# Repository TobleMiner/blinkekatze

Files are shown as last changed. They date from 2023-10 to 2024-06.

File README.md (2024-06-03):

Blinkekatze 😺
=============

This is a replacement PCB for one version of cat themed night lights available via various online retailers.

It adds a number of RGB LEDs, sensors and wireless connectivity, enabling an interactive light display synchronized over a large number of Blinkekatzen.

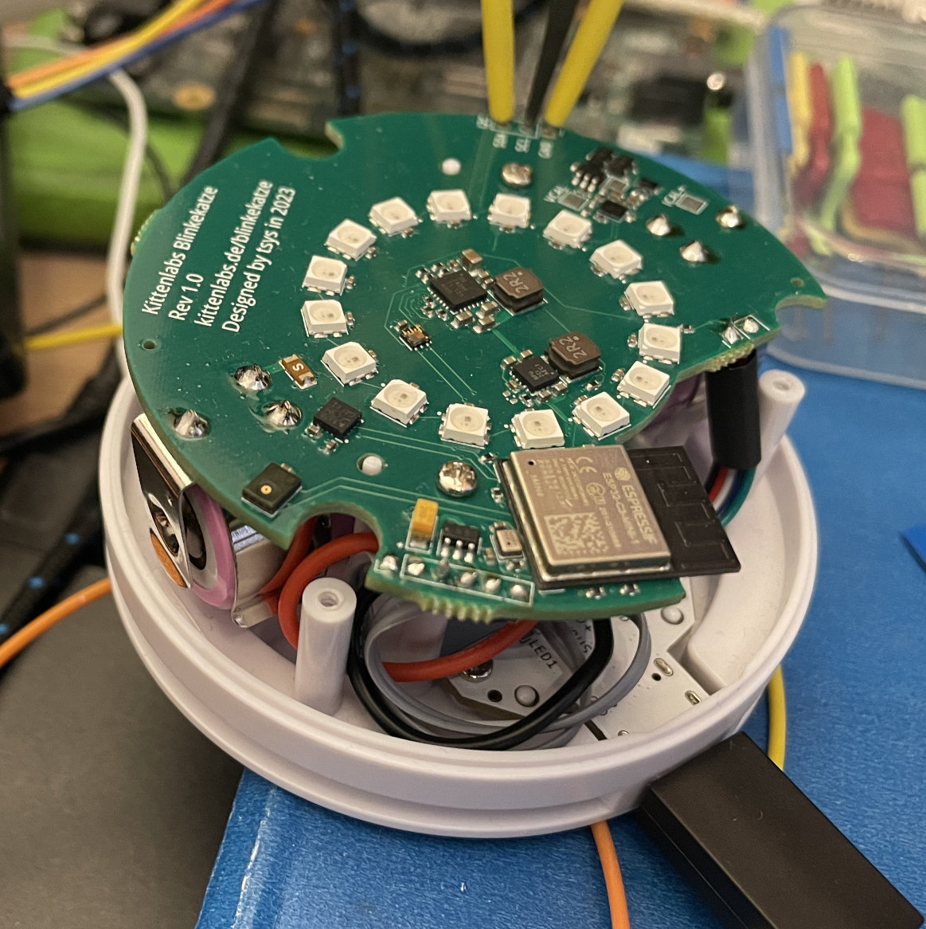
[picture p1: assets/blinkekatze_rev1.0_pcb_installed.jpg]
Photo of Rev1.0 mainboard


Inspired by the wonderful [derf](https://github.com/derf)

# Architecture

The Blinkekatze is comprised of three PCBs:
 - The main board (this directory)
 - The USB board (located in [/usb-board](/usb-board))
 - The original power- and mode-switch board from the nightlight

## Mainboard

The main board contains most elements critical to device operation. At its heart is an ESP32-C3 for control.

The ESP32-C3 is accompanied by the following peripherals:
 - 16 super bright, individually controllable RGB LEDs (effectively ~12bit RGB color control)
 - High precision battery gauge for accurate capacity tracking and runtime estimation
 - Accelerometer and barometer to detect user interaction
 - Ambient light sensor enabling automatic brightness control
 - Efficient buck-mode battery charger

The main board also includes a MEMS PDM microphone that could be used for audio synchronization of lighting effects.
However note the ESP32-C3 is missing hardware PDM to PCM conversion capability.

## USB board

The USB board replaces the original board used for charging in the nightlight. It offers USB connectivity to the
ESP32-C3 and contains two indicator LEDs visible through the bottom of the Blinkekatze.

To facilitate easy, solderless assembly mainboard and USB board are connected by a 5cm long 16 pin flat flex cable with opposite side contacts.

# Ordering PCBs

All PCBs required to build Blinkekatzen can be ordered fully assembled from JLCPCB. The necessary fabrication files are located in [/fab](/fab) for
the main board and [/usb-board/fab](/usb-board/fab). It is recommended to always use the latest revision available in those folders.  
When ordering the PCBs they should be ordered as 1.6mm 4 layers for the mainboard and 1.6mm 2 layers for the USB board.

## PCB assembly

In addition to the bare PCBs JLCPCB also offers an assembly service. The BOM and component centroid files required for assembly are also located in
[/fab](/fab) and [/usb-board/fab](/usb-board/fab) respectively.  
When ordering assembly for the main PCB cost can be reduced significantly by choosing to populate only the top side of the PCB and later assembling
the battery contacts (BTT1 and BTT2) on the bottom side by yourself manually. Those are the only parts on the bottom side of the PCB. Also microphone
U6 is best left unpopulated since a lack of proper PDM to PCM support on the ESP32-C3 makes it mostly unusable.

### Additional required electronic components

Apart from the components assembled by JLCPCB the following parts are required:  
 - 2x MYOUNG MY-18650-01 battery contacts (if not assembled by JLCPCB, see previous section)
 - 1x 5cm 16pin 0.5mm pitch flat flex cable (e.g. C5151983 on LCSC)
 - 1x 18650 battery (Samsung INR18650-35E recommended)

### JLCPCB assembly component availability

Sometimes components required for assembly are out of stock at JLCPCB. In this case the parts have to be ordered fist through
JLCPCB's parts preorder service. Usually all required parts can be preordered in small quantities and will be available within
a couple of days.

# Assembling the Blinkekatzen

## Preparing the PCB

If the battery contacts were not assembled through JLCPCB they need to be soldered. The overall fit of the battery is best with the
contacts installed as far apart as possible within the throughholes. Special care should be taken to ensure the battery contacts are
not soldered at an angle but lie flat on the PCB. Otherwise the battery might not snap into the contacts properly.

## Preparing the housing

In the first step the rubber boot needs to be removed. The puck containing all electronics can either be pulled out to the bottom or
first pushed into the puck and then removed.  
Next the transparent diffuser on top of the puck can be removed by undoing the three screws (relatively long and skinny #0 Phillips
head screwdriver required) and pulling up on the diffuser.  

## Removing the original PCBs

The original PCB is held in place with two screws. After undoing the screws the PCB can be pivoted to the side and the battery unplugged.  
The original USB board also needs to be removed by undoing the two screws holding it in place.  
Finally the PCB can be freed by desoldering the six connections on the original main PCB that go to the switch board in the bottom of the case.
Since the switch board will be reused desoldering rather than cutting the wire can save some time later.  

## Modifying the case

After removal of the original main PCB the case needs to be modified slightly to accommodate the new battery. To make space for the new battery
and battery holder snip out the two thin plastic walls with the half circle shaped cutouts the old battery was resting on using flush cutters.

## Installing the USB board

The first new component to be installed in the housing is the new USB board. Since this board will be installed with the USB connector and flat
flex connector facing down the flat flex cable needs to be connected to this board first. To connect the flat flex cable the latch on the
connector must be flipped up and the cable then inserted with the contacts facing down. The cable is then secured by closing the latch again.  
Now the USB board can be installed in the housing and secured in place with the two screws.

## Installing the new main PCB

As a first step the two outermost contacts of the ribbon cable earlier desoldered from the original main PCB are soldered to the power key header
J1 on the new main PCB (labeled PWR_ON and VBAT, polarity does not matter). Then the battery is installed (here polarity does very much matter). **NEVER**
may batteries without or with a damaged insulating sleeve be used with this device. The battery contacts will short out such batteries!  
After folding back the flat flex cable so it remains free and is not trapped under the battery the new main PCB is fixed in place with two screws.  
As a final step the flat flex cable is now installed into the flat flex connector on the new main PCB in the same manner as on the USB board.

## Firmware flashing

Please see [blinkekatze-firmware](https://github.com/TobleMiner/blinkekatze-firmware) for details on firmware flashing.

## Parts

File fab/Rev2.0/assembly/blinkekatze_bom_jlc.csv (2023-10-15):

Comment | Designator | Footprint | LCSC Part #
B+ | BTT1 | MY-18650-01_flat-top | C2979183
B- | BTT2 | MY-18650-01_flat-top | C2979183
100nF | C1,C2,C3,C4,C5,C6,C7,C8,C9,C10,C11,C12,C13,C14,C15,C16,C73,C20,C21,C22,C23,C24,C26,C27 | C_0402_1005Metric | C1525
10uF | C17 | CP_EIA-3216-18_Kemet-A | C7171
1uF | C18,C19,C66,C67,C68,C69,C70,C25,C33 | C_0402_1005Metric | C52923
22uF | C28 | C_0805_2012Metric | C45783
4.7uF | C29 | C_0402_1005Metric | C23733
10uF | C30,C31,C32 | C_0603_1608Metric | C19702
10uF | C65,C71,C72,C74,C75 | C_0402_1005Metric | C15525
SK6812MINI-012 | D1,D2,D3,D4,D5,D6,D7,D8,D9,D10,D11,D12,D13,D14,D15,D16 | XXXX12-X1 | C2886570
4A | F1 | Fuse_1206_3216Metric | C187596
USB board | J4 | 0.5K-QX-16PWB_16Pin_0.5mm | C2919481
2.2uH | L4,L2 | L_Taiyo-Yuden_MD-4040 | C98361
AO3400A | Q1,Q2 | SOT-23 | C20917
10k | R1,R21,R22,R43,R9,R13,R14,R15,R16,R17,R18 | R_0402_1005Metric | C25744
100R | R2,R5,R6,R7,R10,R11,R12 | R_0402_1005Metric | C25076
220R | R3 | R_0402_1005Metric | C25091
10mR | R4 | R_0805_2012Metric | C5185583
1k | R8 | R_0402_1005Metric | C11702
330 | R19,R20 | R_0402_1005Metric | C25104
100k | R23,R44 | R_0402_1005Metric | C25741
4.7k | R45,R46 | R_0402_1005Metric | C25900
0R | R48 | R_0402_1005Metric | C17168
ESP32-C3-MINI-1 | U1 | ESP32-C3-MINI-1 | C2934569
BQ27546 | U2 | DSBGA-15_BQ27546_I2C_1.95x2.6mm_P0.5mm | C528629
SRV05-4 | U3 | SOT-23-6 | C85364
FM2113 | U4 | SOT-23-6 | C2832124
SPL06-001 | U5 | LGA-8_2x2.5mm_P0.65mm | C2684428
~ | U6 | ST_HCLGA-4LD_3x4mm | C503097
LTR-303ALS-01 | U7 | Lite-On_LTR-303ALS-01 | C364577
BQ24295 | U8 | QFN-24-1EP_4x4mm_P0.5mm_EP2.7x2.7mm | C165144
TPS63001 | U9 | Texas_DRC0010J_ThermalVias.3 | C28060
LIS3DH | U10 | LGA-16_3x3mm_P0.5mm_LayoutBorder3x5y | C15134

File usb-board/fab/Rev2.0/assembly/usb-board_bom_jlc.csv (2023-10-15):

Comment | Designator | Footprint | LCSC Part #
1nF | C1 | C_1206_3216Metric | C9196
GRN | D1 | LED_0603_1608Metric | C72043
RED | D2 | LED_0603_1608Metric | C2286
USB_C_Receptacle_USB2.0 | J2 | USB_C_Receptacle_Palconn_UTC16-G | C167321
Mainboard | J3 | 0.5K-QX-16PWB_16Pin_0.5mm | C2919481
5.1k | R1,R2 | R_0402_1005Metric | C25905
100k | R3 | R_0805_2012Metric | C149504

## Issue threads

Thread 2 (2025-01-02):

Replacement parts for SPL06-001 and CUM0805-15FR010?

ConiKost, 2025-01-02:
Unfortunately JLCPCB cannot get anymore the parts ```SPL06-001``` and ```CUM0805-15FR010```. As for ```SPL06-001```, they could get it, if you buy at minimum 10000pcs, which is way to much. But it looks like, that this part is EOL. Also part ```CUM0805-15FR010``` cannot be bought and they also cannot get a quotation.

Are there any recommended replacement parts, if possible?

patrick246, 2025-01-02:
I'm currently ordering too. I found some SPL06-001 from someone selling their parts. Minimum preorder volume for me is 14, not 10k. @LeoDJ found STE0805MW75R010F as a replacement for CUM0805-15FR010. It has a lower power rating, but should work.

ConiKost, 2025-01-02:
> I found some SPL06-001 from someone selling their parts. Minimum preorder volume for me is 14, not 10k.

Sure? Because JLCPCB also says 14pcs at minimum, but after order, the can't get them, as 10000pcs is minimum. But JLCPCB still lists 14pcs as order minimum..

patrick246, 2025-01-03:
I haven't actually gone through with ordering, as JLC suggested someone selling their idle parts.
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
There still seem to be some available.

TobleMiner, 2025-01-03:
Hey!
At first glance the GZP6816D seems to be a suitable replacement (footprint compatible as far as I can tell!) for the SPL06-001. However I have never tested that sensor before so it might be that there are some unforeseen issues.

For the 10mR shunt any 0805 10mR resistor will work fine. I would recommend keeping the tolerance to a maximum of 1% so that the battery capacity measurement results stay reasonably accurate. STE0805MW75R010F is a suitable replacement.

ConiKost, 2025-01-03:
JLC also replied to me with following parts should be compatible as replacement:
SPL06-001: [C83291](https://jlcpcb.com/parts/componentSearch?searchTxt=C83291) and [C22388663](https://jlcpcb.com/parts/componentSearch?searchTxt=C22388663)
CUM0805-15FR010: [C163089](https://jlcpcb.com/parts/componentSearch?searchTxt=C163089), [C601083](https://jlcpcb.com/parts/componentSearch?searchTxt=C601083) and [C346480](https://jlcpcb.com/parts/componentSearch?searchTxt=C346480)

Any opinion on that?

TobleMiner, 2025-01-03:
Oh, those are nice finds!
Especially the WF282A (C22388663) seems to be fully compatible to the SPL06-001. The BMP280 is somewhat similar in capabilities but not fully compatible.
The shunts are fine, too.

Closed 2025-04-13.

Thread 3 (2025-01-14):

Firmware does not find BQ27546?

ConiKost, 2025-01-14:
Since I placed an order on JLCPCB for something else, I also did order two assembled Blinkekatze PCBs (with BOM as intended) for some fun.

Can I run a test without connected switch board? My switchboard seems to have only five wires, not six.

It looks like, that flashing the firmware, it does not find the BQ27546? Could be those PCBs or parts faulty? I have _not_ enabled flashing ti battery gauge. Or could be no firmware flashed at all on the BQ27546, so it's not detected? Is there any cheaper alternative to EV2400, if this could be the case?

Monitor indicates some crashing:
```
Executing action: monitor
Running idf_monitor in directory /home/xxx/Downloads/blinkekatze-firmware
Executing "/root/.espressif/python_env/idf5.1_py3.10_env/bin/python /home/xxx/Downloads/blinkekatze-firmware/esp-idf/tools/idf_monitor.py -p /dev/ttyACM0 -b 115200 --toolchain-prefix riscv32-esp-elf- --target esp32c3 --revision 4 --decode-panic backtrace /home/xxx/Downloads/blinkekatze-firmware/build/blinkekatze.elf -m '/root/.espressif/python_env/idf5.1_py3.10_env/bin/python' '/home/xxx/Downloads/blinkekatze-firmware/esp-idf/tools/idf.py' '-p' '/dev/ttyACM0'"...
--- esp-idf-monitor 1.5.0 on /dev/ttyACM0 115200
--- Quit: Ctrl+] | Menu: Ctrl+T | Help: Ctrl+T followed by Ctrl+H
 (31ESP-ROM:esp32c3-api1-20210207
Build:Feb  7 2021
rst:0x15 (USB_UART_CHIP_RESET),boot:0x9 (SPI_FAST_FLASH_BOOT)
Saved PC:0x4004c0d4
SPIWP:0xee
mode:DIO, clock div:1
load:0x3fcd5820,len:0x1704
load:0x403cc710,len:0x938
load:0x403ce710,len:0x2ef4
entry 0x403cc710
I (24) boot: ESP-IDF v5.1.5 2nd stage bootloader
I (24) boot: compile time Jan 14 2025 13:31:15
I (25) boot: chip revision: v0.4
I (27) boot.esp32c3: SPI Speed      : 80MHz
I (32) boot.esp32c3: SPI Mode       : DIO
I (37) boot.esp32c3: SPI Flash Size : 4MB
I (42) boot: Enabling RNG early entropy source...
I (47) boot: Partition Table:
I (51) boot: ## Label            Usage          Type ST Offset   Length
I (58) boot:  0 phy_init         RF data          01 01 00009000 00001000
I (65) boot:  1 otadata          OTA data         01 00 0000a000 00002000
I (73) boot:  2 nvs              WiFi data        01 02 0000c000 00004000
I (80) boot:  3 factory          factory app      00 00 00010000 00150000
I (88) boot:  4 ota_0            OTA app          00 10 00160000 00150000
I (95) boot:  5 ota_1            OTA app          00 11 002b0000 00150000
I (103) boot: End of partition table
I (107) boot: Defaulting to factory image
I (112) esp_image: segment 0: paddr=00010020 vaddr=3c090020 size=2a528h (173352) map
I (148) esp_image: segment 1: paddr=0003a550 vaddr=3fc92e00 size=02b04h ( 11012) load
I (150) esp_image: segment 2: paddr=0003d05c vaddr=40380000 size=02fbch ( 12220) load
I (156) esp_image: segment 3: paddr=00040020 vaddr=42000020 size=8a970h (567664) map
I (252) esp_image: segment 4: paddr=000ca998 vaddr=40382fbc size=0fc98h ( 64664) load
I (271) boot: Loaded app from partition at offset 0x10000
I (271) boot: Disabling RNG early entropy source...
I (271) cpu_start: Unicore app
I (275) cpu_start: Pro cpu up.
I (290) cpu_start: Pro cpu start user code
I (290) cpu_start: cpu freq: 160000000 Hz
I (290) cpu_start: Application information:
I (293) cpu_start: Project name:     blinkekatze
I (299) cpu_start: App version:      fcac468-dirty
I (304) cpu_start: Compile time:     Jan 14 2025 13:31:08
I (310) cpu_start: ELF file SHA256:  40c822aebe1f46a8...
I (316) cpu_start: ESP-IDF:          v5.1.5
I (321) cpu_start: Min chip rev:     v0.4
I (326) cpu_start: Max chip rev:     v1.99
I (331) cpu_start: Chip rev:         v0.4
I (335) heap_init: Initializing. RAM available for dynamic allocation:
I (343) heap_init: At 3FC9BAE0 len 00024520 (145 KiB): DRAM
I (349) heap_init: At 3FCC0000 len 0001C710 (113 KiB): DRAM/RETENTION
I (356) heap_init: At 3FCDC710 len 00002950 (10 KiB): DRAM/RETENTION/STACK
I (363) heap_init: At 50000010 len 00001FD8 (7 KiB): RTCRAM
I (370) spi_flash: detected chip: generic
I  (374) spi_flash: flash io: dio
I (379) sleep: Configure to isolate all GPIO pins in sleep state
I (385) sleep: Enable automatic switching of GPIO sleep configuration
I (392) app_start: Starting scheduler on CPU0
I (397) main_task: Started on CPU0
I (397) main_task: Calling app_main()
I (397) gpio: GPIO[0]| InputEn: 0| OutputEn: 0| OpenDrain: 0| Pullup: 1| Pulldown: 0| Intr:0
I (397) gpio: GPIO[2]| InputEn: 0| OutputEn: 0| OpenDrain: 0| Pullup: 1| Pulldown: 0| Intr:0
E (497) I2C_BUS: I2C bus timeout, trying to unstick bus
I (497) gpio: GPIO[0]| InputEn: 0| OutputEn: 0| OpenDrain: 0| Pullup: 1| Pulldown: 0| Intr:0
I (497) gpio: GPIO[2]| InputEn: 0| OutputEn: 0| OpenDrain: 0| Pullup: 1| Pulldown: 0| Intr:0
E (497) BQ27546: Failed to read gauge id: 263
E (597) I2C_BUS: I2C bus timeout, trying to unstick bus
I (597) gpio: GPIO[8]| InputEn: 0| OutputEn: 0| OpenDrain: 0| Pullup: 1| Pulldown: 0| Intr:0
I (597) gpio: GPIO[2]| InputEn: 0| OutputEn: 0| OpenDrain: 0| Pullup: 1| Pulldown: 0| Intr:0
E (597) BQ27546: Failed to read gauge id: 263
ESP_ERROR_CHECK failed: esp_err_t 0x107 (ESP_ERR_TIMEOUT) at 0x420062a2
--- 0x420062a2: app_main at /home/xxx/Downloads/blinkekatze-firmware/main/src/main.c:267 (discriminator 1)

file: "./main/src/main.c" line 233
func: app_main
expression: bq27546_init(&gauge, &i2c_bus)

abort() was called at PC 0x403871dd on core 0
--- 0x403871dd: _esp_error_check_failed at /home/xxx/Downloads/blinkekatze-firmware/esp-idf/components/esp_system/esp_err.c:50

--- Stack dump detected
Core  0 register dump:
MEPC    : 0x40380694  RA      : 0x403871e8  SP      : 0x3fc9df20  GP      : 0x3fc93600
--- 0x40380694: panic_abort at /home/xxx/Downloads/blinkekatze-firmware/esp-idf/components/esp_system/panic.c:466
0x403871e8: __ubsan_include at /home/xxx/Downloads/blinkekatze-firmware/esp-idf/components/esp_system/ubsan.c:313

TP      : 0x3fc747c8  T0      : 0x37363534  T1      : 0x7271706f  T2      : 0x33323130
S0/FP   : 0x3fc9df5c  S1      : 0x3fc9df40  A0      : 0x3fc9df5c  A1      : 0x3fc9df3e
A2      : 0x00000000  A3      : 0x3fc9df89  A4      : 0x00000001  A5      : 0x3fc9b000
A6      : 0x7a797877  A7      : 0x76757473  S2      : 0x00000000  S3      : 0x3fc9b000
S4      : 0x00000000  S5      : 0x00000000  S6      : 0x00000000  S7      : 0x00000000
S8      : 0x00000000  S9      : 0x00000000  S10     : 0x3fc9b000  S11     : 0x00000000
T3      : 0x6e6d6c6b  T4      : 0x6a696867  T5      : 0x66656463  T6      : 0x62613938
MSTATUS : 0x00001801  MTVEC   : 0x40380001  MCAUSE  : 0x00000007  MTVAL   : 0x00000000
--- 0x40380001: _vector_table at ??:?

MHARTID : 0x00000000

--- Backtrace:

panic_abort (details=details@entry=0x3fc9df5c "abort() was called at PC 0x403871dd on core 0") at /home/xxx/Downloads/blinkekatze-firmware/esp-idf/components/esp_system/panic.c:466
466	    *((volatile int *) 0) = 0; // NOLINT(clang-analyzer-core.NullDereference) should be an invalid operation on targets
#0  panic_abort (details=details@entry=0x3fc9df5c "abort() was called at PC 0x403871dd on core 0") at /home/xxx/Downloads/blinkekatze-firmware/esp-idf/components/esp_system/panic.c:466
#1  0x403871e8 in esp_system_abort (details=details@entry=0x3fc9df5c "abort() was called at PC 0x403871dd on core 0") at /home/xxx/Downloads/blinkekatze-firmware/esp-idf/components/esp_system/port/esp_system_chip.c:84
#2  0x4038df64 in abort () at /home/xxx/Downloads/blinkekatze-firmware/esp-idf/components/newlib/abort.c:38
#3  0x403871e0 in _esp_error_check_failed (rc=<optimized out>, file=<optimized out>, line=<optimized out>, function=<optimized out>, expression=<optimized out>) at /home/xxx/Downloads/blinkekatze-firmware/esp-idf/components/esp_system/esp_err.c:50
#4  0x420062a6 in app_main () at /home/xxx/Downloads/blinkekatze-firmware/main/src/main.c:267
#5  0x00000000 in ?? ()
Backtrace stopped: frame did not save the PC
```

ConiKost, 2025-01-14:
I did a small test and disabled step by step ESP_ERROR_CHECK. After everything disable, the ESP-C3 boots to shell. But it looks like, that nothng is on the i2c bus? So both faultry produced and assembled PCB?

ConiKost, 2025-02-06:
@TobleMiner any idea on that?

Pusty, 2025-02-20:
I'm running into exactly the same situation.

ConiKost, 2025-02-21:
You mean, the bq27546 is not detected, because it's not programmed? The firmware offers some experimental flashing of the it gauge, but I don't know, if that works for empty gauges? Could you pass me your diff, so I could try for myself?

I still wonder, if my PCB is working, because currently, even LEDs do not turn on. But maybe it's too early in init?

Pusty, 2025-02-22:
```diff
diff --git a/main/src/bq27546.c b/main/src/bq27546.c
index 84b90d1..3e83d89 100644
--- a/main/src/bq27546.c
+++ b/main/src/bq27546.c
@@ -32,6 +32,7 @@

 static const char *TAG = "BQ27546";

+/*
 static void lock(bq27546_t *bq) {
 	xSemaphoreTake(bq->lock, portMAX_DELAY);
 }
@@ -151,7 +152,6 @@ esp_err_t bq27546_write_flash_execute_(bq27546_t *bq, const bq27546_flash_op_t *
 			ESP_LOGE(TAG, "Unknown flash operation 0x%02x, op %lu", op->type, (unsigned long)i);
 			return ESP_FAIL;
 		}
-		/* Wait one tick to ensure watchdog stays happy */
 		vTaskDelay(1);
 	}

@@ -274,3 +274,37 @@ esp_err_t bq27546_seal(bq27546_t *bq) {
 esp_err_t bq27546_it_enable(bq27546_t *bq) {
 	return run_subcmd(bq, CMD_CONTROL, SUBCMD_IT_ENABLE);
 }
+*/
+
+int bq27546_get_voltage_mv(bq27546_t *bq) {
+	return 3600;
+}
+
+int bq27546_get_temperature_0_1k(bq27546_t *bq) {
+	return 2931;
+}
+int bq27546_get_time_to_empty_min(bq27546_t *bq) {
+	return 0xffff;
+}
+
+int bq27546_get_full_charge_capacity_mah(bq27546_t *bq) {
+	return 3500;
+}
+
+
+esp_err_t bq27546_get_current_ma(bq27546_t *bq, int *current_ma_out) {
+	uint16_t ucurrent_ma = 100;
+	int16_t current_ma;
+	current_ma = (int16_t)ucurrent_ma;
+	*current_ma_out = current_ma;
+	return 0;
+}
+
+
+int bq27546_get_state_of_charge_percent(bq27546_t *bq) {
+	return 100;
+}
+
+int bq27546_get_state_of_health_percent(bq27546_t *bq) {
+	return 100;
+}
\ No newline at end of file
diff --git a/main/src/main.c b/main/src/main.c
index b9632ba..5ac18dd 100644
--- a/main/src/main.c
+++ b/main/src/main.c
@@ -224,9 +224,15 @@ void app_main(void) {
 	usb_init();

 	i2c_bus_t i2c_bus;
-	i2c_bus_init(&i2c_bus, I2C_NUM_0, 0, 2, 100000);
+	//i2c_bus_init(&i2c_bus, I2C_NUM_0, 0, 2, 100000);
+    i2c_bus_init(&i2c_bus, I2C_NUM_0, 8, 2, 100000);
+
+    is_rev2 = true;
 	bq27546_t gauge;
-	esp_err_t err =	bq27546_init(&gauge, &i2c_bus);
+
+
+    //ESP_ERROR_CHECK(bq27546_init(&gauge, &i2c_bus));
+	/*esp_err_t err =	bq27546_init(&gauge, &i2c_bus);
 	if (err) {
 		i2c_bus_deinit(&i2c_bus);
 		i2c_bus_init(&i2c_bus, I2C_NUM_0, 8, 2, 100000);
@@ -266,6 +272,7 @@ void app_main(void) {
 	int current_ma;
 	ESP_ERROR_CHECK(bq27546_get_current_ma(&gauge, &current_ma));
 	ESP_LOGI(TAG, "Battery current: %dmA", current_ma);
+    */

 	spi_bus_config_t spi_bus_cfg = {
 		.mosi_io_num = is_rev2 ? 3 : 7,

```

The LEDs are off by default, I need to either add the switch / connection for that or run the "ignore_power_switch" command for them to turn on

ConiKost, 2025-02-22:
Thanks. I applied your patch on vanilla source, but it looks like, that I have more problems, as boot continues and fails then not finding spl06 (barometer). Does your find it?

```
Rebooting...
ESP-ROM:esp32c3-api1-20210207
Build:Feb  7 2021
rst:0x3 (RTC_SW_SYS_RST),boot:0xd (SPI_FAST_FLASH_BOOT)
Saved PC:0x40380640
0x40380640: esp_restart_noos_dig at /home/xxx/Downloads/blinkekatze-firmware/esp-idf/components/esp_system/esp_system.c:64 (discriminator 1)
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
Pusty, 2025-02-23:
Hmm, yeah for me it works after initializing i2c as rev2 with `i2c_bus_init(&i2c_bus, I2C_NUM_0, 8, 2, 100000);`

ConiKost, 2025-02-23:
Well, I guess my produces PCBs must be faulty..

ConiKost, 2025-04-13:
Since no reply from developer, closing here..

Closed 2025-04-13.

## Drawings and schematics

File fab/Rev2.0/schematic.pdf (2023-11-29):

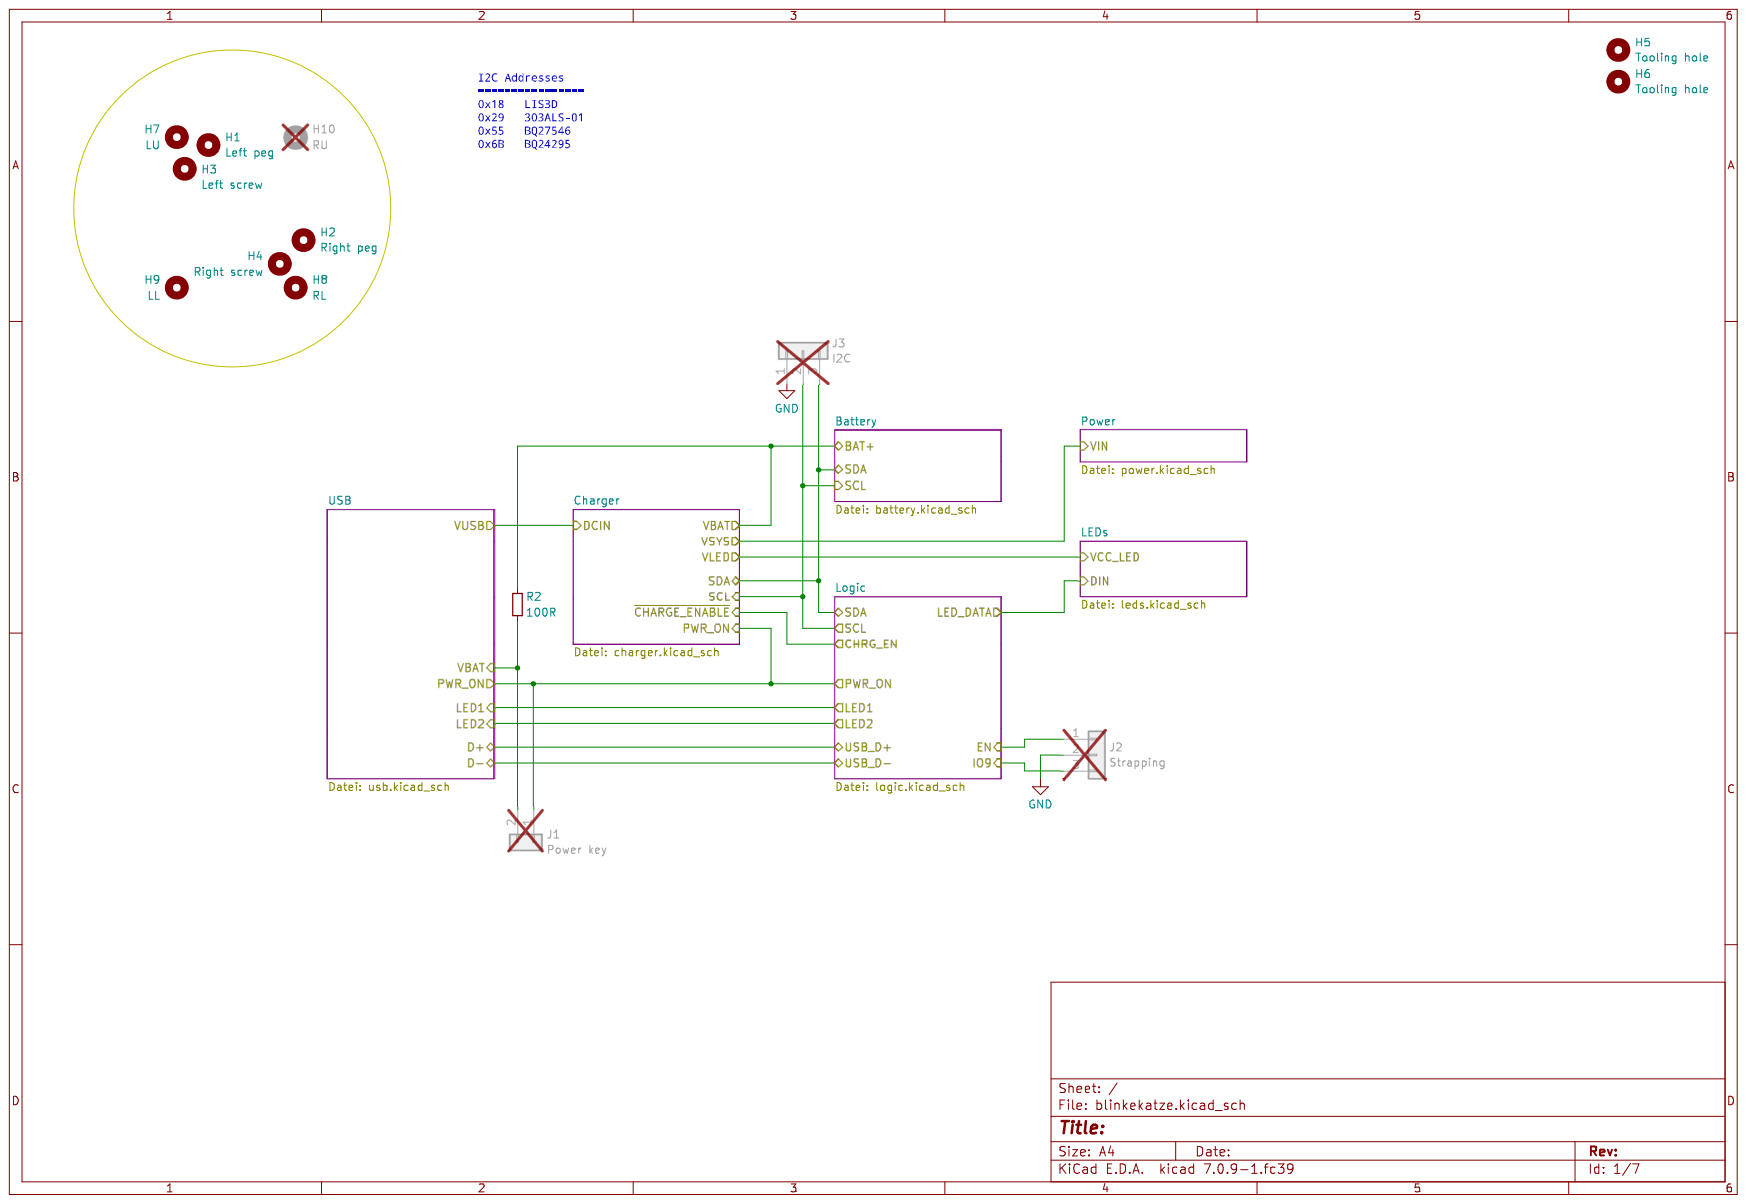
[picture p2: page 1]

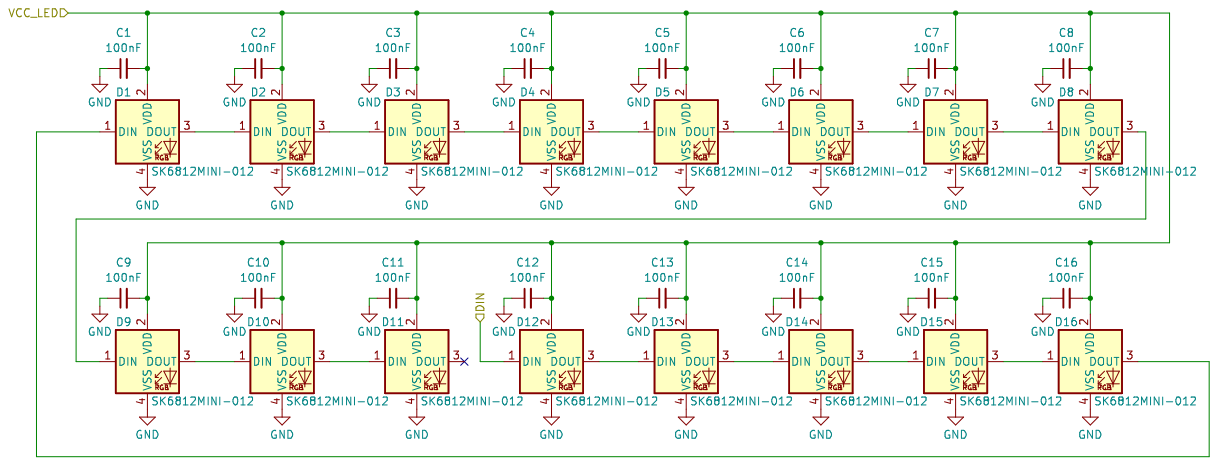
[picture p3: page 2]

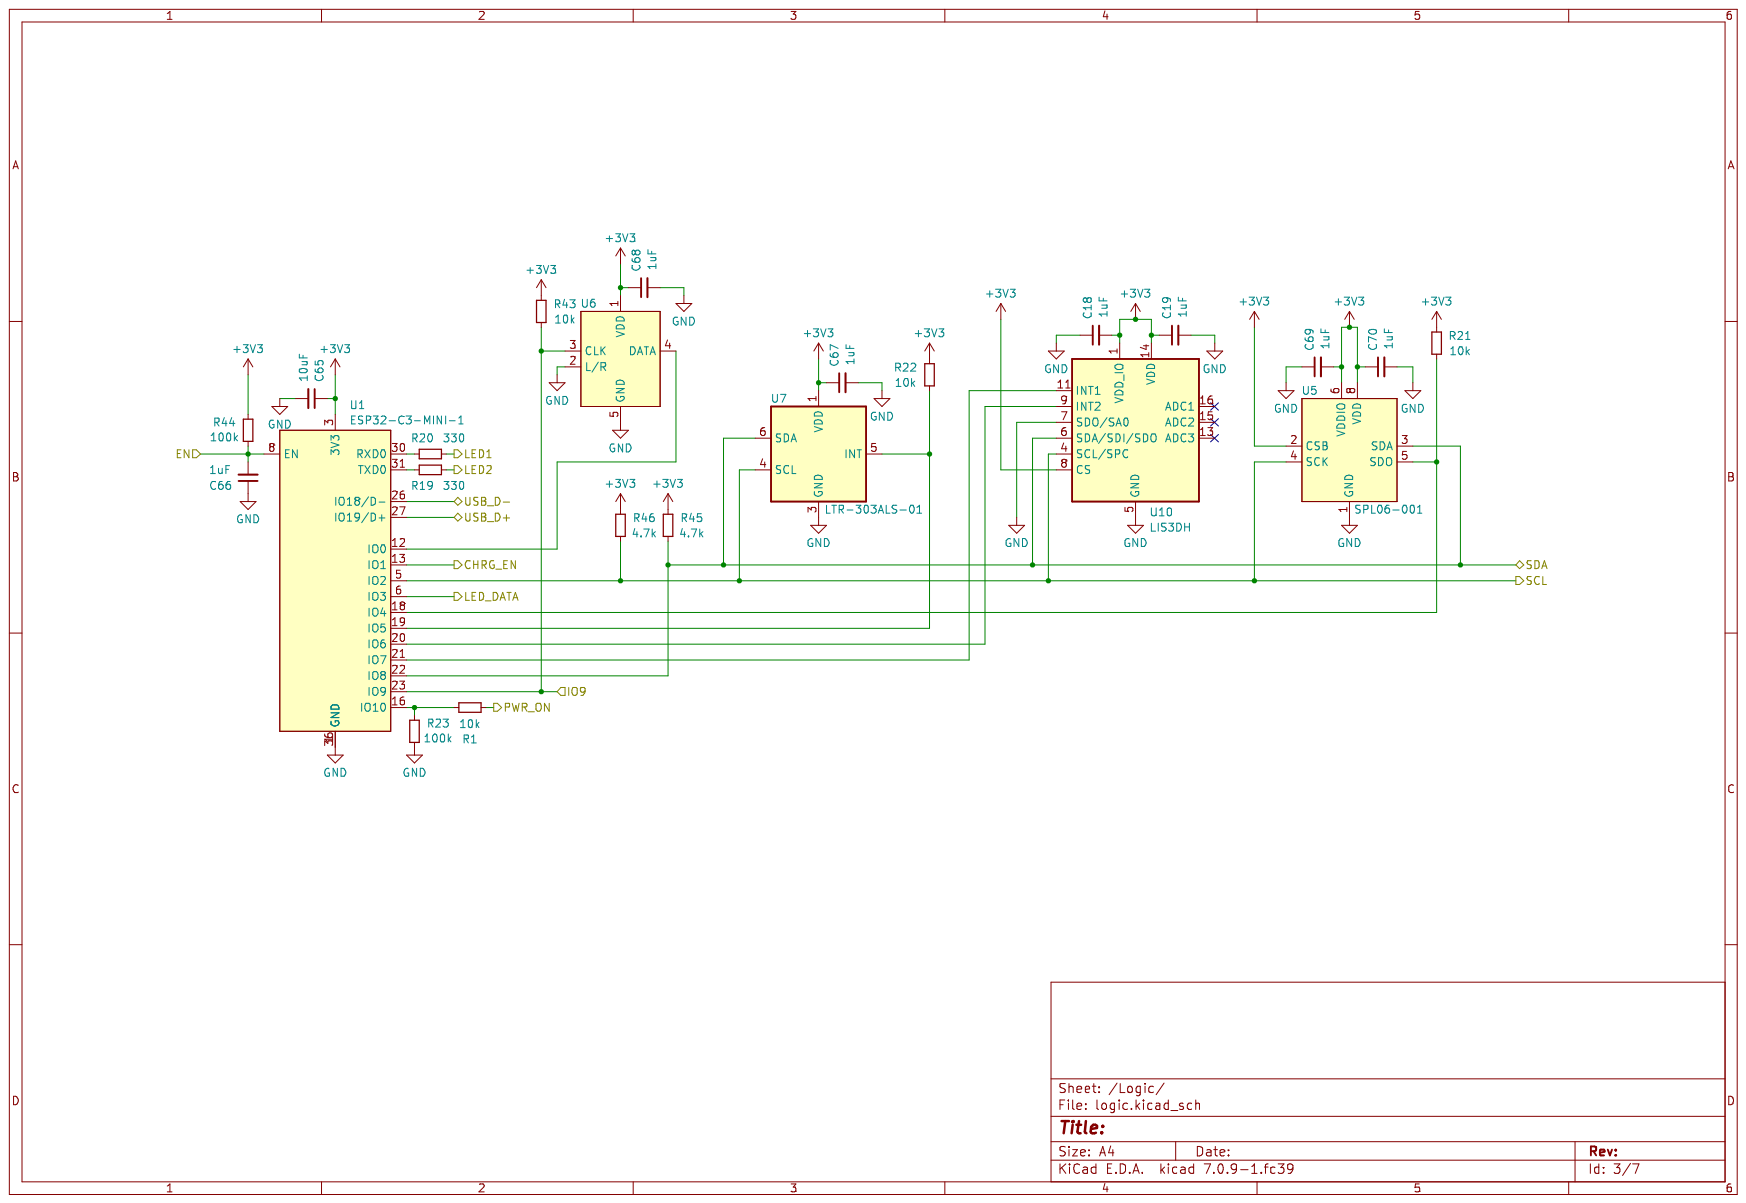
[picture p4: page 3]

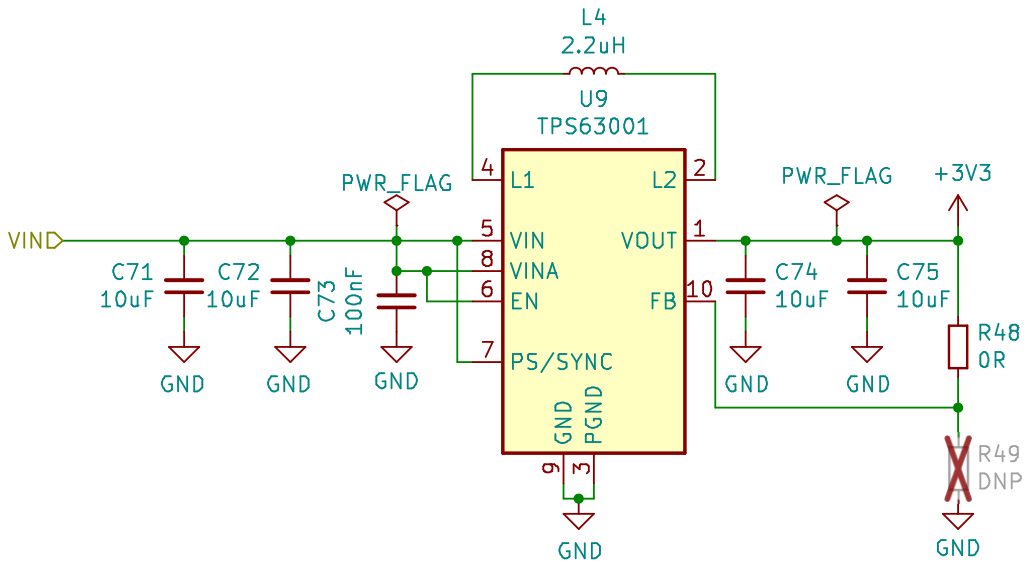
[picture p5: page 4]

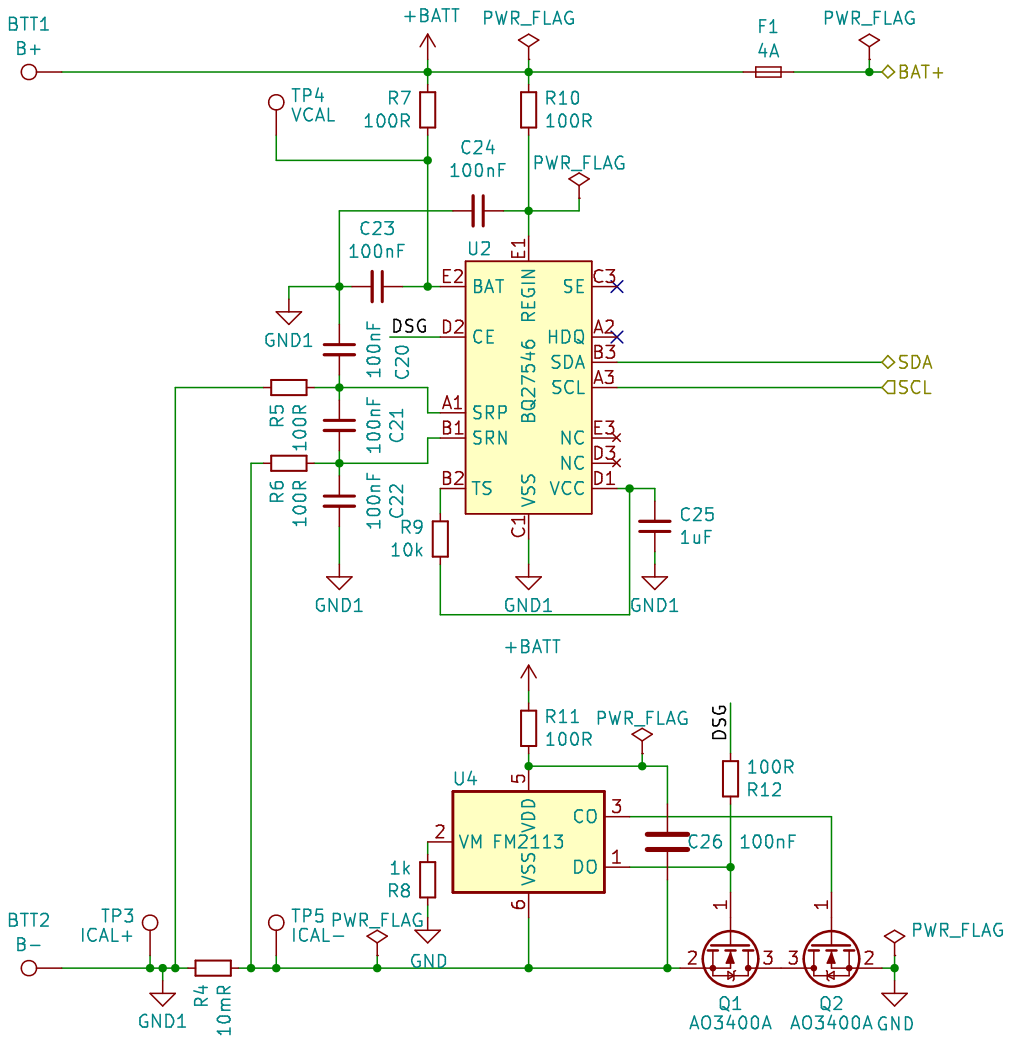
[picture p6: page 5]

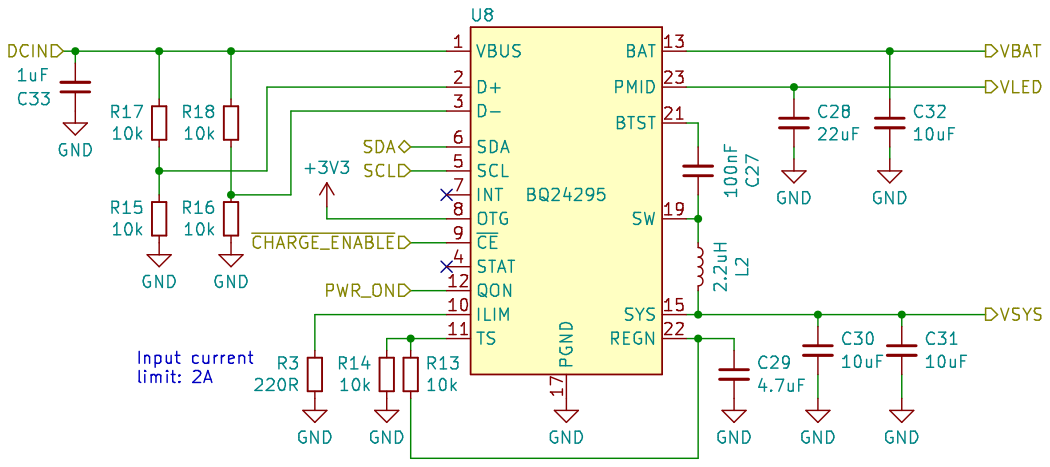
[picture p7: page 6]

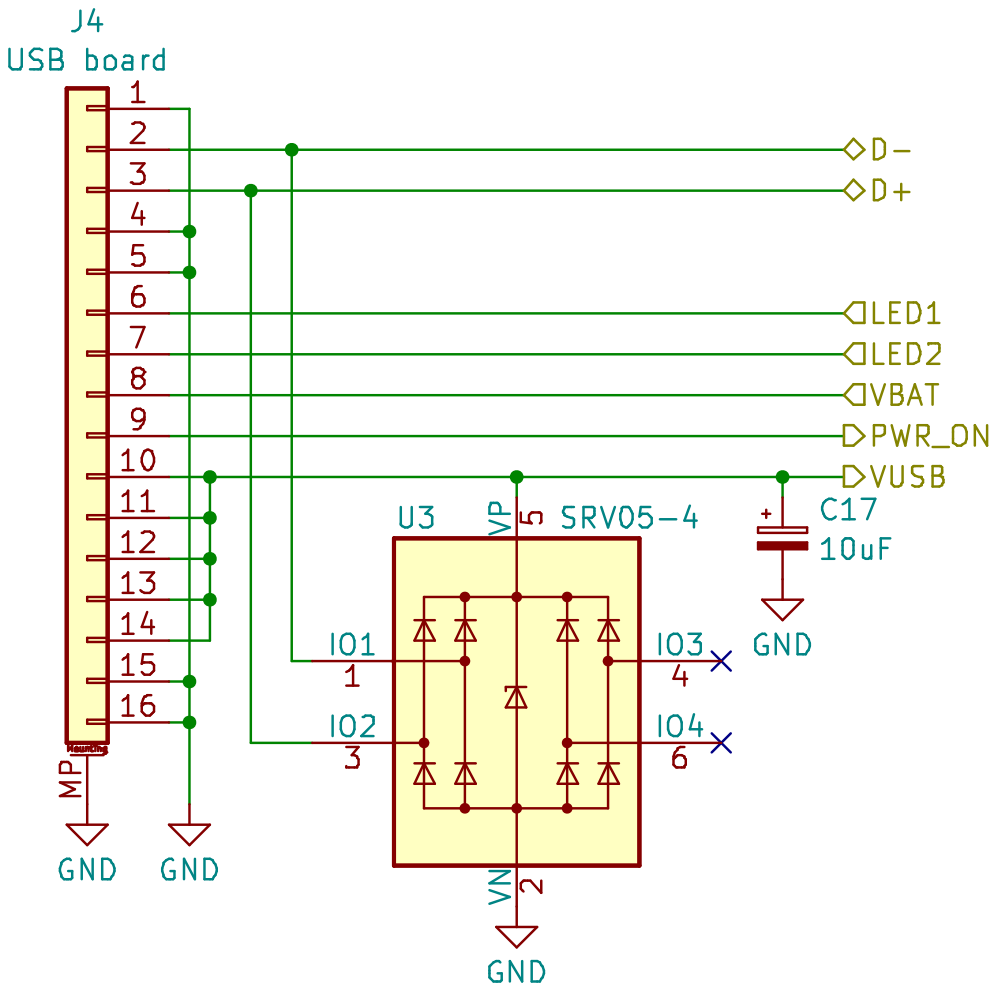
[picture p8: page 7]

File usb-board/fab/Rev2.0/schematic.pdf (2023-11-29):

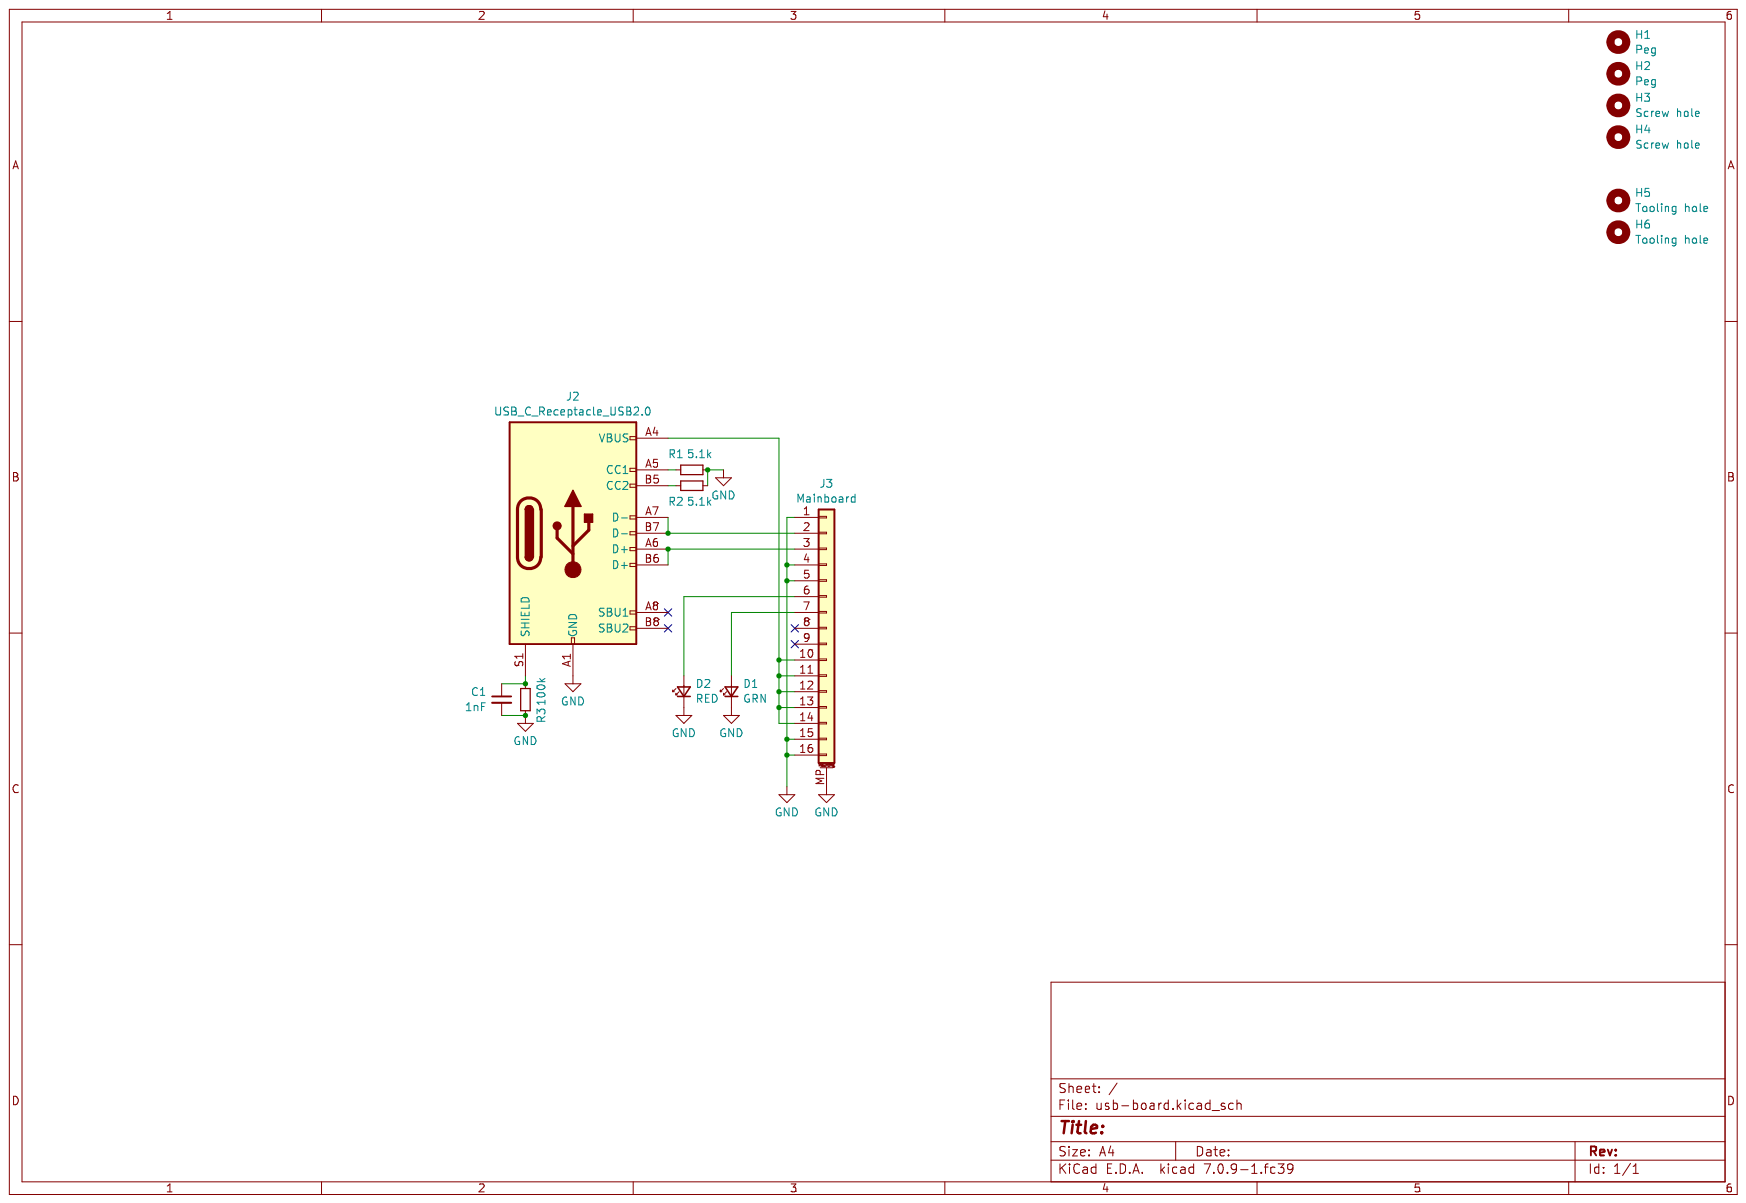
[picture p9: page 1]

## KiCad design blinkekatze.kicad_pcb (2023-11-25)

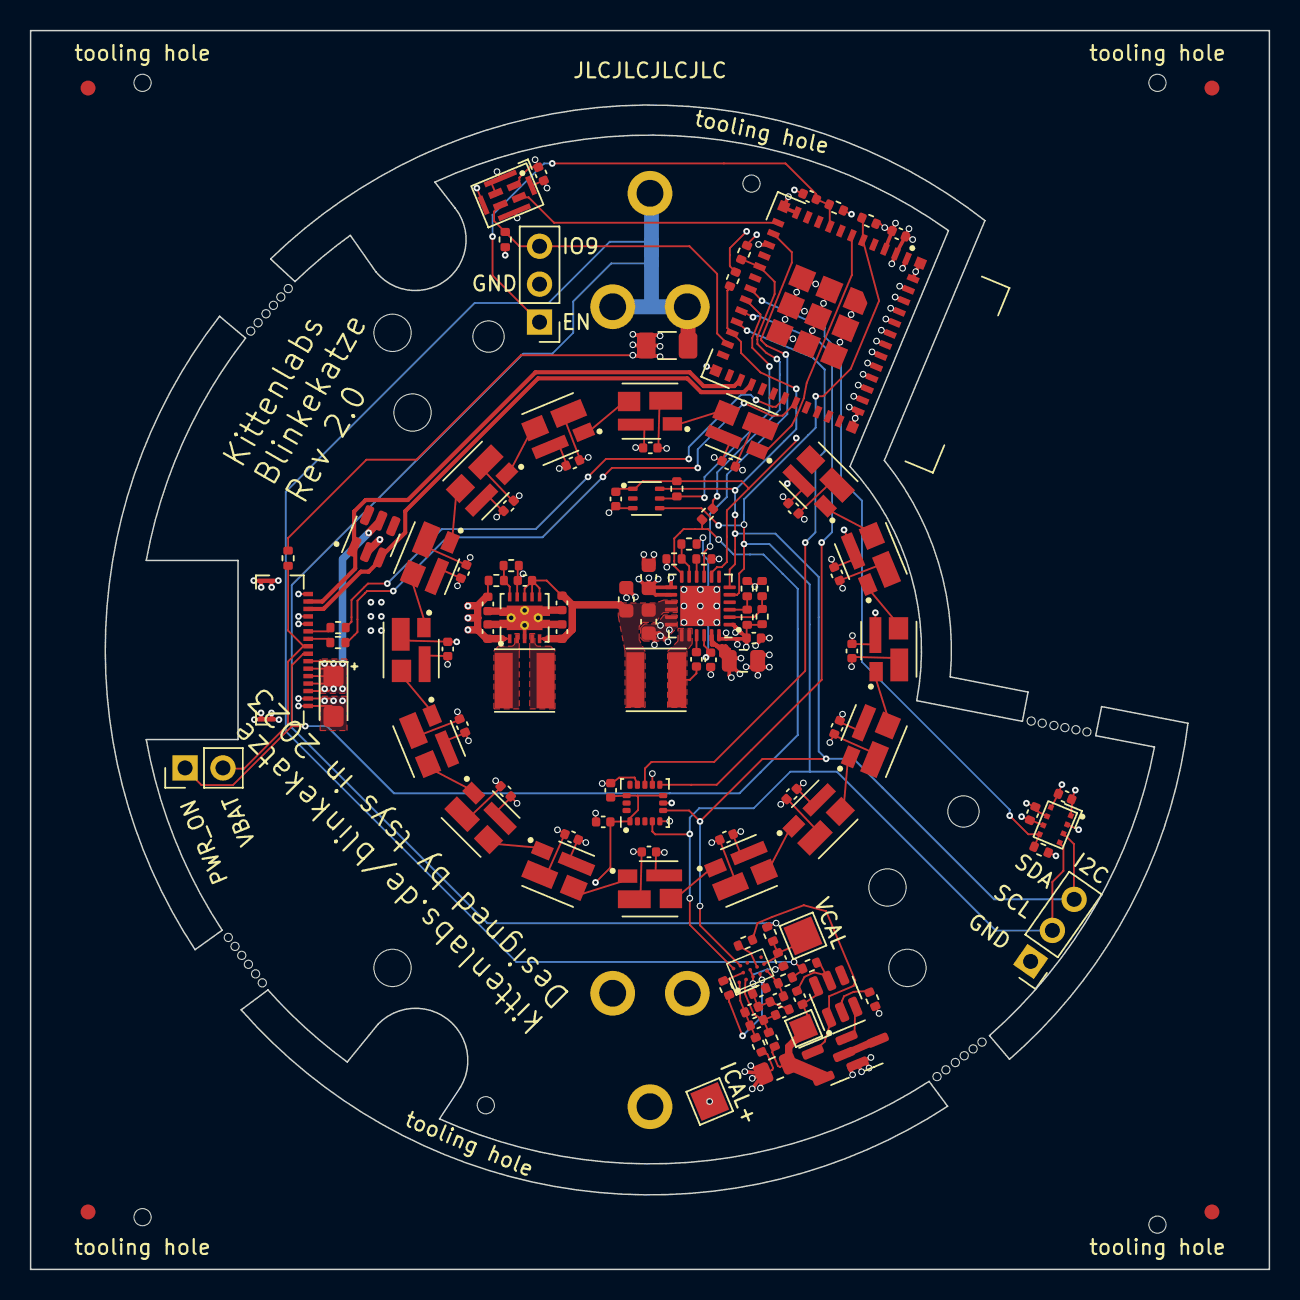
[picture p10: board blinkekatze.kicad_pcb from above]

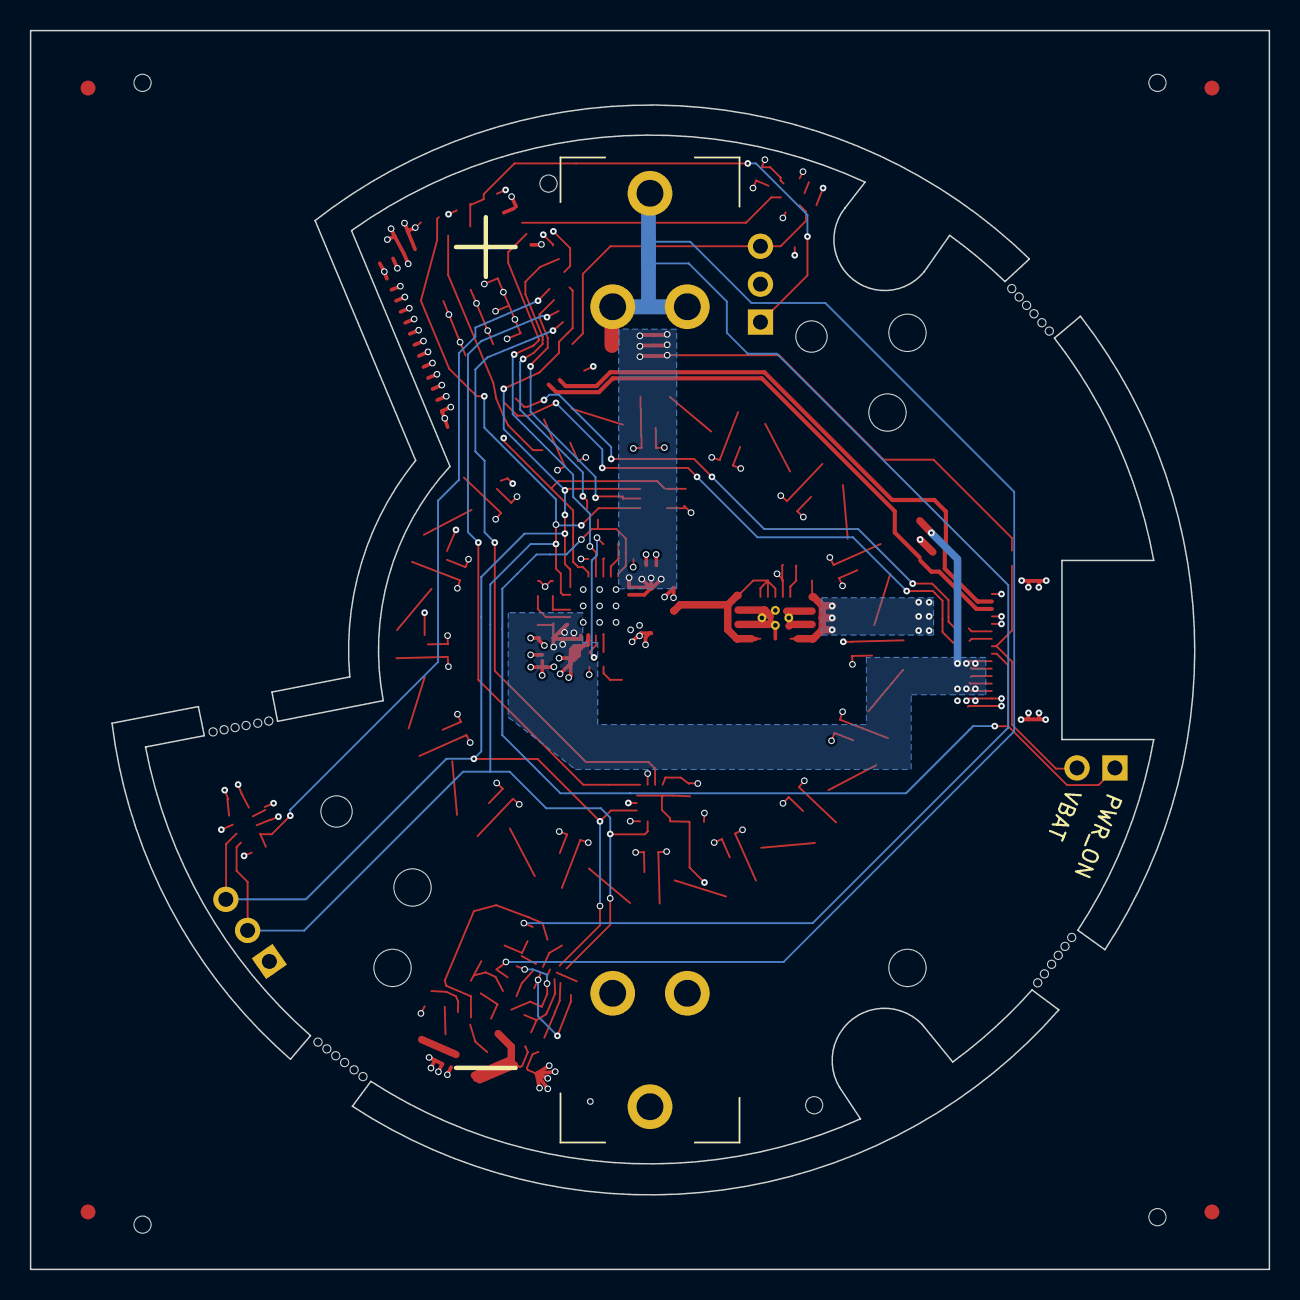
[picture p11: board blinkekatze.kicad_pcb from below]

Board: 4 copper layers, 83.0 x 83.0 mm, 122 parts (2 on the bottom side), 66 nets.

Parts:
BTT1: B+; MY-18650-01_flat-top
BTT2: B-; MY-18650-01_flat-top
C1, C2, C3, C4, C5, C6, C7, C8, C9, C10, C11, C12, C13, C14, C15, C16, C20, C21, C22, C23, C24, C26, C27, C73: 100nF; C_0402_1005Metric
C17: 10uF; CP_EIA-3216-18_Kemet-A
C18, C19, C25, C33, C66, C67, C68, C69, C70: 1uF; C_0402_1005Metric
C28: 22uF; C_0805_2012Metric
C29: 4.7uF; C_0402_1005Metric
C30, C31, C32: 10uF; C_0603_1608Metric
C65, C71, C72, C74, C75: 10uF; C_0402_1005Metric
D1, D2, D3, D4, D5, D6, D7, D8, D9, D10, D11, D12, D13, D14, D15, D16: SK6812MINI-012; XXXX12-X1
F1: 4A; Fuse_1206_3216Metric
H1: Left peg; MountingHole_2.1mm
H2: Right peg; MountingHole_2.1mm
H3: Left screw; MountingHole_2.5mm
H4: Right screw; MountingHole_2.5mm
H5, H6: Tooling hole; ToolingHole_JLCSMT
H7: LU; MountingHole_2.5mm
H8: RL; MountingHole_2.5mm
H9: LL; MountingHole_2.5mm
J1: Power key; PinHeader_1x02_P2.54mm_Vertical
J2: Strapping; PinHeader_1x03_P2.54mm_Vertical
J3: I2C; PinHeader_1x03_P2.54mm_Vertical
J4: USB board; 0.5K-QX-16PWB_16Pin_0.5mm
L2, L4: 2.2uH; L_Taiyo-Yuden_MD-4040
Q1, Q2: AO3400A; SOT-23
R1, R9, R13, R14, R15, R16, R17, R18, R21, R22, R43: 10k; R_0402_1005Metric
R2, R5, R6, R7, R10, R11, R12: 100R; R_0402_1005Metric
R3: 220R; R_0402_1005Metric
R4: 10mR; R_0805_2012Metric
R8: 1k; R_0402_1005Metric
R19, R20: 330; R_0402_1005Metric
R23, R44: 100k; R_0402_1005Metric
R45, R46: 4.7k; R_0402_1005Metric
R48: 0R; R_0402_1005Metric
R49: DNP; R_0402_1005Metric
TP3: ICAL+; TestPoint_Pad_2.0x2.0mm
TP4: VCAL; TestPoint_Pad_2.0x2.0mm
TP5: ICAL-; TestPoint_Pad_1.5x1.5mm
U1: ESP32-C3-MINI-1
U2: BQ27546; DSBGA-15_BQ27546_I2C_1.95x2.6mm_P0.5mm
U3: SRV05-4; SOT-23-6
U4: FM2113; SOT-23-6
U5: SPL06-001; LGA-8_2x2.5mm_P0.65mm
U6: ST_HCLGA-4LD_3x4mm
U7: LTR-303ALS-01; Lite-On_LTR-303ALS-01
U8: BQ24295; QFN-24-1EP_4x4mm_P0.5mm_EP2.7x2.7mm
U9: TPS63001; Texas_DRC0010J_ThermalVias.3
U10: LIS3DH; LGA-16_3x3mm_P0.5mm_LayoutBorder3x5y

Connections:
+3V3: C18.2, C19.1, C65.1, C67.1, C68.1, C69.2, C70.1, C74.2, C75.2, R21.1, R22.1, R43.1, R44.1, R45.1, R46.1, R48.1, U1.3 (3V3), U5.2 (CSB), U5.6 (VDDIO), U5.8 (VDD), U6.1 (VDD), U7.1 (VDD), U8.8 (OTG), U9.1 (VOUT), U10.1 (VDD_IO), U10.8 (CS), U10.14 (VDD)
+BATT: BTT1.1, F1.1, R7.1, R10.1, R11.1
/Battery/BAT+: C32.1, F1.2, R2.2, U8.13 (BAT), U8.14 (BAT)
/Battery/DSG: R12.2, U2.D2 (CE)
/Battery/SCL: J3.2, R46.2, U1.5 (IO2), U2.A3 (SCL), U5.4 (SCK), U7.4 (SCL), U8.5 (SCL), U10.4 (SCL/SPC)
/Battery/SDA: J3.3, R45.2, U1.22 (IO8), U2.B3 (SDA), U5.3 (SDA), U7.6 (SDA), U8.6 (SDA), U10.6 (SDA/SDI/SDO)
/Charger/PWR_ON: J1.1, J4.9, R1.1, U8.12 (QON)
/Charger/VLED: C1.2, C2.2, C3.2, C4.2, C5.2, C6.2, C7.2, C8.2, C9.2, C10.2, C11.2, C12.2, C13.2, C14.2, C15.2, C16.2, C28.1, D1.2 (VDD), D2.2 (VDD), D3.2 (VDD), D4.2 (VDD), D5.2 (VDD), D6.2 (VDD), D7.2 (VDD), D8.2 (VDD), D9.2 (VDD), D10.2 (VDD), D11.2 (VDD), D12.2 (VDD), D13.2 (VDD), D14.2 (VDD), D15.2 (VDD), D16.2 (VDD), U8.23 (PMID)
/Charger/VSYS: C30.1, C31.1, C71.2, C72.2, C73.2, L2.2, U8.15 (SYS), U8.16 (SYS), U9.5 (VIN), U9.6 (EN), U9.7 (PS/SYNC), U9.8 (VINA)
/Charger/~CHARGE_ENABLE: U1.13 (IO1), U8.9 (~CE)
/LEDs/DIN: D12.1 (DIN), U1.6 (IO3)
/Logic/EN: C66.2, J2.1, R44.2, U1.8 (EN)
/Logic/IO9: J2.3, R43.2, U1.23 (IO9), U6.3 (CLK)
/Logic/LED1: J4.6, R20.1
/Logic/LED2: J4.7, R19.1
/Logic/USB_D+: J4.3, U1.27 (IO19/D+), U3.3 (IO2)
/Logic/USB_D-: J4.2, U1.26 (IO18/D-), U3.1 (IO1)
/USB/VBAT: J1.2, J4.8, R2.1
GND: C1.1, C2.1, C3.1, C4.1, C5.1, C6.1, C7.1, C8.1, C9.1, C10.1, C11.1, C12.1, C13.1, C14.1, C15.1, C16.1, C17.2, C18.1, C19.2, C28.2, C29.2, C30.2, C31.2, C32.2, C33.1, C65.2, C66.1, C67.2, C68.2, C69.1, C70.2, C71.1, C72.1, C73.1, C74.1, C75.1, D1.4 (VSS), D2.4 (VSS), D3.4 (VSS), D4.4 (VSS), D5.4 (VSS), D6.4 (VSS), D7.4 (VSS), D8.4 (VSS), D9.4 (VSS), D10.4 (VSS), D11.4 (VSS), D12.4 (VSS), D13.4 (VSS), D14.4 (VSS), D15.4 (VSS), D16.4 (VSS), J2.2, J3.1, J4.1, J4.4, J4.5, J4.15, J4.16, J4.MP (MountPin), Q2.2 (S), R3.2, R8.1, R14.2, R15.2, R16.2, R23.2, R49.2, U1.1 (GND), U1.2 (GND), U1.11 (GND), U1.14 (GND), U1.36 (GND), U1.37 (GND), U1.38 (GND), U1.39 (GND), U1.40 (GND), U1.41 (GND), U1.42 (GND), U1.43 (GND), U1.44 (GND), U1.45 (GND), U1.46 (GND), U1.47 (GND), U1.48 (GND), U1.49 (GND), U1.50 (GND), U1.51 (GND), U1.52 (GND), U1.53 (GND), U3.2 (VN), U5.1 (GND), U5.7 (GND), U6.2 (L/R), U6.5 (GND), U7.3 (GND), U8.17 (PGND), U8.18 (PGND), U8.25 (PGND), U9.3 (PGND), U9.9 (GND), U9.11 (PGND), U10.5 (GND), U10.7 (SDO/SA0), U10.10 (GND), U10.12 (GND)
GND1: BTT2.1, C20.1, C22.2, C23.2, C24.2, C25.1, R4.1, R5.1, TP3.1, U2.C1 (VSS), U2.C2 (VSS)
unnamed: C27.1, L2.1, U8.19 (SW), U8.20 (SW)
unnamed: D1.1 (DIN), D16.3 (DOUT)
unnamed: D1.3 (DOUT), D2.1 (DIN)
unnamed: D2.3 (DOUT), D3.1 (DIN)
unnamed: D3.3 (DOUT), D4.1 (DIN)
unnamed: D4.3 (DOUT), D5.1 (DIN)
unnamed: D5.3 (DOUT), D6.1 (DIN)
unnamed: D6.3 (DOUT), D7.1 (DIN)
unnamed: D7.3 (DOUT), D8.1 (DIN)
unnamed: D8.3 (DOUT), D9.1 (DIN)
unnamed: D9.3 (DOUT), D10.1 (DIN)
unnamed: D10.3 (DOUT), D11.1 (DIN)
unnamed: D12.3 (DOUT), D13.1 (DIN)
unnamed: D13.3 (DOUT), D14.1 (DIN)
unnamed: D14.3 (DOUT), D15.1 (DIN)
unnamed: D15.3 (DOUT), D16.1 (DIN)
unnamed: Q1.3 (D), Q2.3 (D)
unnamed: Q1.1 (G), R12.1, U4.1 (DO)
unnamed: C26.1, Q1.2 (S), R4.2, R6.1, TP5.1, U4.6 (VSS)
unnamed: Q2.1 (G), U4.3 (CO)
unnamed: U1.12 (IO0), U6.4 (DATA)
unnamed: R21.2, U1.18 (IO4), U5.5 (SDO)
unnamed: R22.2, U1.19 (IO5), U7.5 (INT)
unnamed: U1.20 (IO6), U10.9 (INT2)
unnamed: U1.21 (IO7), U10.11 (INT1)
unnamed: R1.2, R23.1, U1.16 (IO10)
unnamed: R20.2, U1.30 (RXD0)
unnamed: R19.2, U1.31 (TXD0)
unnamed: C23.1, R7.2, TP4.1, U2.E2 (BAT)
unnamed: C24.1, R10.2, U2.E1 (REGIN)
unnamed: C21.2, C22.1, R6.2, U2.B1 (SRN)
unnamed: C20.2, C21.1, R5.2, U2.A1 (SRP)
unnamed: R9.1, U2.B2 (TS)
unnamed: C25.2, R9.2, U2.D1 (VCC)
unnamed: C26.2, R11.2, U4.5 (VDD)
unnamed: R8.2, U4.2 (VM)
unnamed: C27.2, U8.21 (BTST)
unnamed: R15.1, R17.2, U8.2 (D+)
unnamed: R16.1, R18.2, U8.3 (D-)
unnamed: R3.1, U8.10 (ILIM)
unnamed: C29.1, R13.2, U8.22 (REGN)
unnamed: R13.1, R14.1, U8.11 (TS)
unnamed: R48.2, R49.1, U9.10 (FB)
unnamed: L4.1, U9.4 (L1)
unnamed: L4.2, U9.2 (L2)
VBUS: C17.1, C33.2, J4.10, J4.11, J4.12, J4.13, J4.14, R17.1, R18.1, U3.5 (VP), U8.1 (VBUS), U8.24 (VBUS)

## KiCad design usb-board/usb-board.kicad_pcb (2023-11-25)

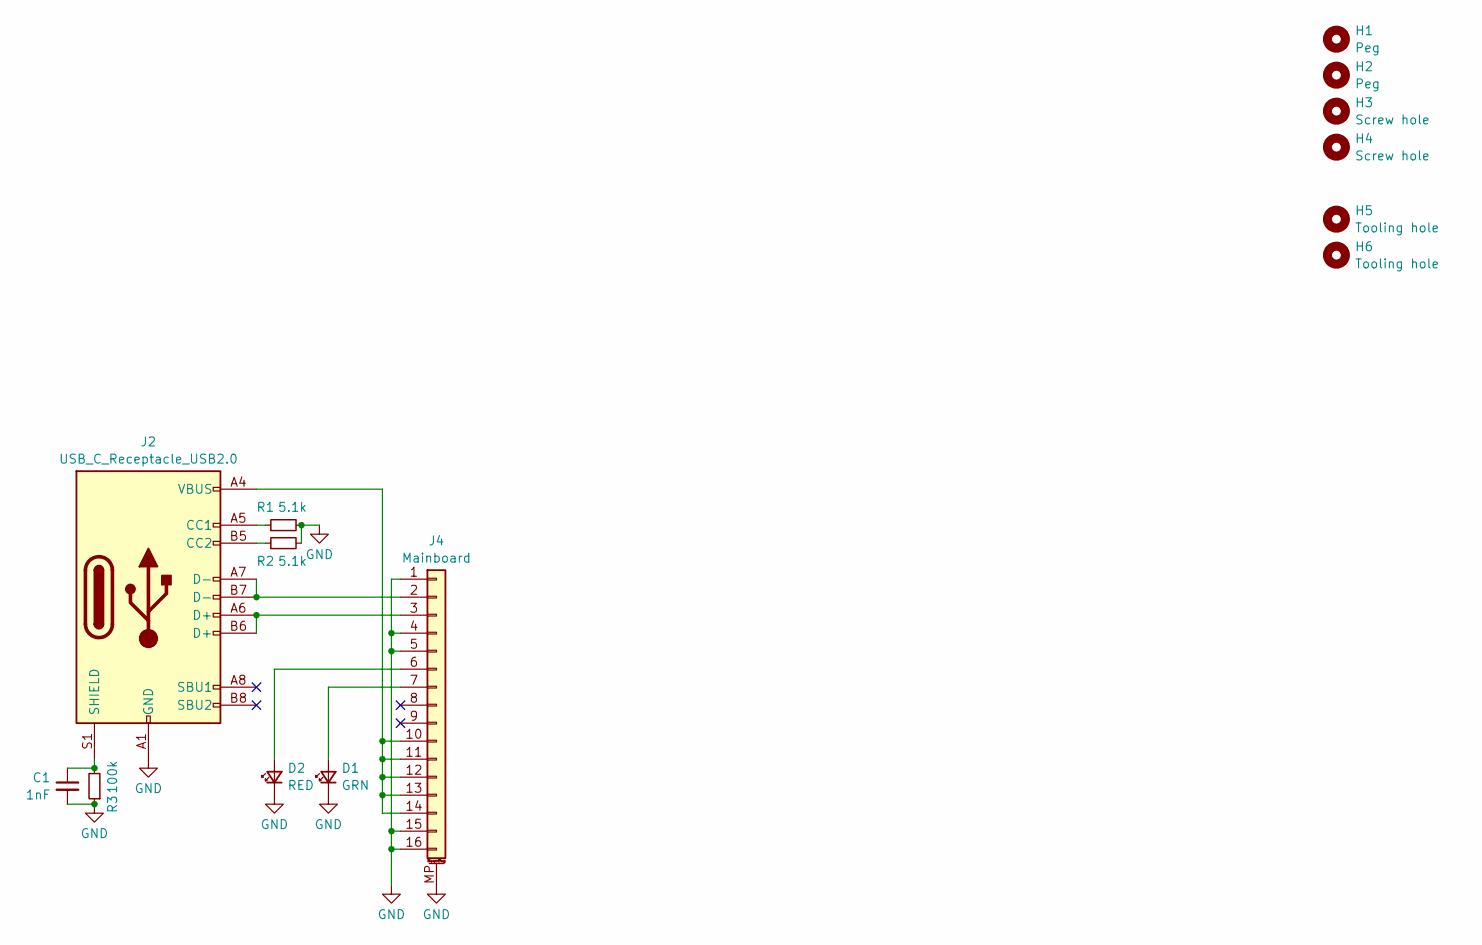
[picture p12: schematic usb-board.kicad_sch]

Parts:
C1: 1nF; C_1206_3216Metric; LCSC C9196
D1: GRN; LED_0603_1608Metric; LCSC C72043
D2: RED; LED_0603_1608Metric; LCSC C2286
H1, H2: Peg; MountingHole_2.1mm
H3, H4: Screw hole; MountingHole_2.5mm
H5, H6: Tooling hole; ToolingHole_JLCSMT
J2: USB_C_Receptacle_USB2.0; USB_C_Receptacle_Palconn_UTC16-G; LCSC C167321
J4: Mainboard; 0.5K-QX-16PWB_16Pin_0.5mm; LCSC C2919481
R1, R2: 5.1k; R_0402_1005Metric; LCSC C25905
R3: 100k; R_0805_2012Metric; LCSC C149504

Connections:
GND: C1.2, D1.1 (K), D2.1 (K), J2.A1 (GND), J2.A12 (GND), J2.B1 (GND), J2.B12 (GND), R1.2, R2.2, R3.1; also elsewhere on the board
unnamed 1: D1.2 (A); also elsewhere on the board
unnamed 2: D2.2 (A); also elsewhere on the board
unnamed: J2.A5 (CC1), R1.1
unnamed: J2.B5 (CC2), R2.1
unnamed: C1.1, J2.S1 (SHIELD), R3.2
unnamed 6: J2.A7 (D-), J2.B7 (D-); also elsewhere on the board
unnamed 7: J2.A6 (D+), J2.B6 (D+); also elsewhere on the board
unnamed 8: J2.A4 (VBUS), J2.A9 (VBUS), J2.B4 (VBUS), J2.B9 (VBUS); also elsewhere on the board

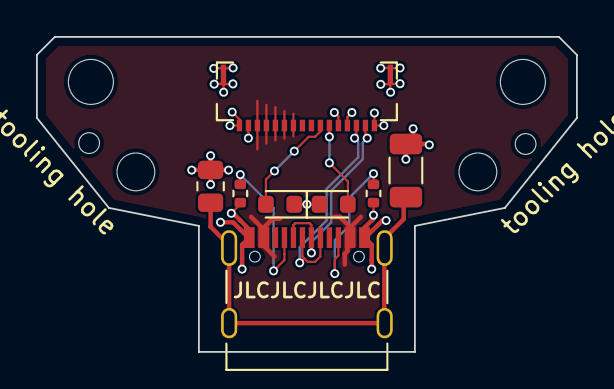
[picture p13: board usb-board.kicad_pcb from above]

Board: 2 copper layers, 30.0 x 17.5 mm, 14 parts (0 on the bottom side), 9 nets.

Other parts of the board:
J3: Mainboard; 0.5K-QX-16PWB_16Pin_0.5mm

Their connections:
GND: J3.1, J3.4, J3.5, J3.15, J3.16, J3.MP (MountPin); also elsewhere on the board
unnamed 1: J3.7; also elsewhere on the board
unnamed 2: J3.6; also elsewhere on the board
unnamed 6: J3.2; also elsewhere on the board
unnamed 7: J3.3; also elsewhere on the board
unnamed 8: J3.10, J3.11, J3.12, J3.13, J3.14; also elsewhere on the board

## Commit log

2023-09-08 Add gauge schematic and partial charger schematic
    [battery.kicad_sch, charger.kicad_sch, logic.kicad_sch]
2023-09-08 Fix duplicate pin assignment on pressure sensor
2023-09-08 Finish preliminary charger and logic schematic
    [blinkekatze.kicad_pcb, blinkekatze.kicad_sch, charger.kicad_sch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]
2023-09-08 Aesthetic top level schematic fixes
    [blinkekatze.kicad_pcb, blinkekatze.kicad_sch, usb.kicad_sch]
2023-09-10 Add list of 1S charger chips
    [charger.kicad_sch, logic.kicad_sch]
2023-09-11 Finish rough layout
    [battery.kicad_sch, blinkekatze.kicad_pcb, blinkekatze.kicad_sch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]
2023-09-11 Add 3D model to battery gauge
2023-09-11 Hide silkscreen designators
    [blinkekatze.kicad_pcb]
2023-09-11 JLCPCB DFM
    [blinkekatze.kicad_pcb, blinkekatze.kicad_sch]
2023-09-11 Add accelerometer
    [blinkekatze.kicad_pcb, blinkekatze.kicad_sch, logic.kicad_sch]
2023-09-11 Add copper fill keepouts below poorly shielded inductors
    [blinkekatze.kicad_pcb]
2023-09-11 Add pin 1 marker to ambient light sensor and accelerometer
    [blinkekatze.kicad_pcb]
2023-09-11 Add I2C test connector
    [blinkekatze.kicad_pcb, blinkekatze.kicad_sch, logic.kicad_sch]
2023-09-11 Add battery polarity indicators
    [blinkekatze.kicad_pcb]
2023-09-11 Remove duplicate pin 36 from ESP32-C3-MINI-1
2023-09-11 Reduce battery protection IC VDD impedance
    Reduce from 470R to 100R in line with manufacturers recommendation
    [battery.kicad_sch]
2023-09-11 Update ESP32-C3-MINI-1 symbol in schematic
    [logic.kicad_sch]
2023-09-11 Fix incorrect vertical pad spacing on SK6812-MINI-X1 footprint
2023-09-11 Update SK6812-MINI-X1 footprints
    [blinkekatze.kicad_pcb]
2023-09-11 Add simple USB board replacement
    [usb-board.kicad_pcb, usb-board.kicad_sch]
2023-09-11 usb-board: improve VBUS connection
    [usb-board.kicad_pcb]
2023-09-11 Add pin 1 marker to barometric pressure sensor
    [blinkekatze.kicad_pcb]
2023-09-13 Add informational comment on input current limit to schematic
    [charger.kicad_sch]
2023-10-11 lib: add flat-top variant of MY-18650-01 battery holder
2023-10-11 usb-board: add silkscreen markings
    [usb-board.kicad_pcb, usb-board.kicad_sch]
2023-10-11 battery: use flat top battery holder
    [battery.kicad_sch]
2023-10-11 logic: connect pressure sensor via I2C
    [logic.kicad_sch]
2023-10-11 Add additional mounting holes for micro USB cat nightlight variant
    [blinkekatze.kicad_sch]
2023-10-11 Partial rip-up of old design
    [blinkekatze.kicad_pcb]
2023-10-15 Relayout board to fit constraints of Micro USB Blinkekatzen
    [blinkekatze.kicad_pcb, blinkekatze.kicad_sch, leds.kicad_sch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]
2023-10-15 DFM and 2A input current limit
    [blinkekatze.kicad_pcb, charger.kicad_sch]
2023-10-15 Change mainboard connector to FFC type
    [usb-board.kicad_pcb, usb-board.kicad_sch]
2023-10-15 usb-board: fix FFC pinout
    [usb-board.kicad_pcb, usb-board.kicad_sch]
2023-10-15 usb-board: update silkscreen designators
    - Remove second JLCJLCJLCJLC designator
    - Change revision indicator to Rev2.0
    [usb-board.kicad_pcb]
2023-10-15 usb-board: add fabrication files
    [usb-board-B_Cu.gbl, usb-board-B_Mask.gbs, usb-board-B_Paste.gbp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]
2023-10-15 logic: update LCSC partnumbers
    [logic.kicad_sch]
2023-10-15 Update copper fill
    [blinkekatze.kicad_pcb]
2023-10-15 Add fabrication files
    [blinkekatze-B_Cu.gbl, blinkekatze-B_Mask.gbs, blinkekatze-B_Paste.gbp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]
2023-11-25 Add FFC 3D model
    [blinkekatze.kicad_pcb, usb-board.kicad_pcb]
2023-11-29 Add schematic exports
2024-01-21 README: provie more detailed assembly instructions
